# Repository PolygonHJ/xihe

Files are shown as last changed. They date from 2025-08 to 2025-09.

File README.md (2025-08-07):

# Xihe
**Xihe** is a self-sustaining, ultra-low-power sensing platform designed for long-lifetime deployments with zero maintenance. Powered by ambient energy sources such as solar or background RF, the system stores energy in supercapacitors until it reaches a threshold sufficient to activate, sense, and transmit data wirelessly. Once depleted, it enters a dormant state and repeats the cycle.

The system is designed to be as small and unobtrusive as possible, enabling it to be placed in an environment, monitor passively, and be forgotten—both visually and in terms of maintenance.

## System Overview
The platform consists of:

### 1. **Main Board — "Xihe-Core"**
- Hosts the energy harvesting and power management circuitry,
- Includes high-capacitance supercapacitor storage,
- Integrates a **Seeed XIAO nRF54L15** module for BLE/Zigbee communication,
- Provides a modular connector interface for sensor boards (I²C, SPI, UART, Analogue),
- Manages energy thresholds and system wakeup logic.

### 2. **Sensor Modules**
- Plug-in sensor boards for flexibility,
- Operate only during active energy windows to minimize load,
- Interchangeable to allow flexibility in deployment.

### 3. **Energy Storage Modules**
- Optional add-ons for extended runtime or energy reserve (Supercapacitors or Batteries),
- Connect to the side or bottom of the board for flexibility,
- Extend active life at the cost of increased physical size.

## Features
- ⚡ **Ambient Energy Harvesting**: Solar (single-cell) supported; RF harvesting planned,
- 🔋 **Supercapacitor-Based Power Storage**: Maintenance-free,
- 📡 **Low-Power Wireless Comms**: BLE/Zigbee-ready for periodic broadcast,
- 🧩 **Modular Sensing**: Swappable sensor boards and energy modules for application-specific deployments,
- 🔄 **Cyclic Operation**: Charge → Activate → Sense → Transmit → Sleep,
- ♻️ **Designed for Longevity**: No batteries, no wires, no maintenance

## Use Cases
The project is intended for low-effort, low-maintenance monitoring in home automation or other low-frequency sensing environments.

Example sensing applications:
- Light  
- Temperature  
- Humidity  
- Moisture  
- Open/Close (e.g. reed switch)  

## Status
The hardware is under active development. No hardware for software has been produced or tested yet.

# Future Ideas
- Energy storage modules,
- RF energy harvesting,
- Modularise harvesting and energy storage sections.

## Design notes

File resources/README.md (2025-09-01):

# Resources

- [Energy Harvester](./energy_harvester/): files related to the energy harvester chip (such as calculations).
- [PcbWay Manufacturing Files](./pcbway_manufacturing_rules/): reference rules file with PcbWays manufacturing capabilities.
- [Projects](./projects/): reference projects and exmaples;
  - [Proposal](./projects/Proposal/) is an initial concept design for a single sided board to test hardware with. This primarily was to test the USB-SWD circuit more easily, but the replacement on this sub-circuit with the Xiao nRF54L15 means the test design is less required.
  - [Xiao nRF54L15 Module](https://wiki.seeedstudio.com/xiao_nrf54l15_sense_getting_started/), an nRF54L15 module from seeed studio used for this project.
  - [BeeLight](https://github.com/Kampi/BeeLight), open source zigbee environment sensor.
  - [Pi Debug Probe](./projects/Pi%20Debugger), onboard USB-SWD schematics and firmware. 
  - [Solar nRF](https://github.com/PocketConcepts/Solar_nRF), low energy harvester example using the BQ25504.

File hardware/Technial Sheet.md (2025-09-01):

# Technical Sheet

> [!warning]
> External energy modules will need to have matching voltages with the on board super capacitor. The capacitor may be desoldered to improve available selection, but charging limits are still set by on-board resistors.

> [!warning]
> Sensor modules must work down to 2.5V to match the potential low threshold of operation as the super capacitor depletes.

## Power
Part selections detailed below. The following assumptions/decisions have been made:
- $50\mu A$ average power consumption (assumption),
- $1mW/cm^2$ power from ambient indoor lightning.

### Charging
Using the [KXOB25-03X4F-TR](https://waf-e.dubudisk.com/anysolar.dubuplus.com/techsupport@anysolar.biz/O18AzRx/DubuDisk/www/Gen3/KXOB25-03X4F%20DATA%20SHEET%2020210127.pdf) would generated approximately $0.25 \times 1m \times 1.39 = 347.5\mu W$.

The capacitor charge time can be calculated with:  
$Pt = \frac{1}{2}C(V_{final}-V_{initial})^2 \rightarrow t = \frac{CV^2}{2 \eta P}$

Where:
- $\eta$: Conversion efficiency; 80%,
- $V_{final}$: Final capacitor voltage; 5.3 based on set limits,
- $V_{initial}$: Initial capacitor voltage, 0V empty, or 2.5V for active system,
- $C$: Energy storage device capacitance; 470mF,
- $P$: Power from solar cell, $347.5\mu W$.

For an empty capacitor:  
$t = \frac{0.47 \times 5.3^2}{2 \times 0.8 \times 0.348m} = 6h36min$ to fully charge.

For the running systme ($V_{initial}=2.5$):  
$t = \frac{0.47 \times (5.3-2.5)^2}{2 \times 0.8 \times 0.348m} = 1h50min$ to fully charge.

> [!note] Note
> Ignores the energy being consumed by the system while charging.

### Discharging
For the system to fully use the available energy in the capacitor:  
$t = \frac{C \times (V_{initial}-V_{final})}{I_{avg}} = \frac{470m \times (5.3-2.5)}{50\mu} \approx 7h20min$

This assumes a $50\mu A$ average current draw based on a [forums post online](https://devzone.nordicsemi.com/f/nordic-q-a/122432/nrf54l15-zigbee---high-current-consumption) for a 1minute period zigbee transmittion achieving similar results.

Using the assumptions of:
- $40ms @ 10mA$ every 5minutes,
- $100ms @ 1mA$ every 5minutes,
- $10\mu A$ standby consumption.

$I_{avg} = \frac{40m \times 10m}{300} + \frac{100m \times 1m}{300} + 10\mu = 12\mu A$  

$t = \frac{470m \times (5.3-2.5)}{12\mu} \approx 30h28min$

## XIAO NRF54L15
The schematic for the [XIAO NRF54L15](https://files.seeedstudio.com/wiki/XIAO_nRF54L15/Getting_Start/nRF54L15_Schematic.pdf) is available online.

### Power
The MCU VDD pins are directly connected to the 3V3 pin on the SoM, therefore supply can be provided externally on this pin. There is some bulk capacitance ($10\mu F$ and $100nF$ here).

The potential leakage current that could feed from the energy storage element to the unrequired system (e.g. debugger) comes through the step down DC `VBUS` to `VSYS_3V3`. The circuit uses a [TPS62843](https://www.ti.com/lit/ds/symlink/tps62843.pdf) with an advertised leakage current of $0 \rarr 45nA$.

### User Button
The user button on the module will be used to put the device in pairing mode.

## Solar Cell
The [KXOB25-03X4F-TR](https://waf-e.dubudisk.com/anysolar.dubuplus.com/techsupport@anysolar.biz/O18AzRx/DubuDisk/www/Gen3/KXOB25-03X4F%20DATA%20SHEET%2020210127.pdf) was chosen for its dimensions and cost that would reasonably fit on the board. See the power section for information on generated power.

The device has:
-  a solar surface area of $0.528 \times 0.659 \times 4 = 1.39cm^2$,
-  25% efficiency.

## Harvester
The harvester is the [BQ25570](https://www.ti.com/lit/ds/symlink/bq25570.pdf). TI was chosen thanks to their good documentation. Of the TI range, the [BQ25570](https://www.ti.com/lit/ds/symlink/bq25570.pdf) offers a built in buck to reduce over-all circuit complexity. It also works with inputs from 100mV up to 5.5V.

The boost ([NRS4012T220MDGJ](https://mm.digikey.com/Volume0/opasdata/d220001/medias/docus/610/NRS4012T220MDGJ_SS.pdf)) and buck ([DFE252012F-100M=P2](https://www.murata.com/~/media/webrenewal/products/inductor/chip/tokoproducts/wirewoundmetalalloychiptype/m_dfe252012f.ashx)) inductors were chosen based on the recommended values in section 8.1.3 of the [BQ25570](https://www.ti.com/lit/ds/symlink/bq25570.pdf) datasheet.

The peripheral capacitors are chosen based on the recommended values in section 8.1.4 of the [BQ25570](https://www.ti.com/lit/ds/symlink/bq25570.pdf) datasheet.

TI provide a design help guide (SLUC484) on their [product page](https://www.ti.com/product/BQ25570#design-tools-simulation) (also found in the resources section of this repository) which is a calculator to help determine required resistor values.

> [!note]
> BoM consolidation on the resistor values can likely be done as a future cost saving exercise as the precision and requirements around these voltage settings is not absolutely strict. The initial values have been chosen to maximise the power saving benefit from the higher sum values.

### MPPT
The harvesting energy source is a solar cell ([KXOB25-03X4F-TR](https://waf-e.dubudisk.com/anysolar.dubuplus.com/techsupport@anysolar.biz/O18AzRx/DubuDisk/www/Gen3/KXOB25-03X4F%20DATA%20SHEET%2020210127.pdf)), therefore the MPPT can be set to 80% which can be achieved on the BQ25570 by tying the `VOC_SAMP` pin to `VSTOR`.

### VBAT_OV
The overvoltage is targeted at 5V5 to maximise the energy that can be stored in a 5V5 capacitor. 

To calculate the required resistor values: $\texttt{VBAT\_OV} = \frac{3}{2} \times 1.21 \left ( 1 + \frac{R_{OV2}}{R_{OV1}}\right )$ and $R_{OV1}+R_{OV2} < 13M\Omega$.

Allowing or a 1% tolerance on the resistors, this sets $R_{OV1}=4.22M\Omega$ and $R_{OV2}=8.2M\Omega$. This leads to a highest possible $\texttt{VBAT\_OV} = 5.4V$ and a nominal $\texttt{VBAT\_OV} = 5.3V$.

> [!warning] Warning
> If a battery module is to be connected, the value of these resistor will most likely need to be changed to support the supplied batteries safe limits.

### VBAT_OK_PROG & VBAT_OK_HYST
The `VBAT_OK_PROG` threshold sets the `VBAT_OK` signal low when the storage device is discharging and drops below the configured threshold.

The `VBAT_OK_HYST` threshold sets the `VBAT_OK` signal high when the storage device is charging and goes above the configured threshold.

The system shall be designed so that `VBAT_OK_PROG` = 3V3 and `VBAT_OK_HYST` = 2V5. Under the condition that the system is only able to charge up to 3V3, due to the available harvestable energy, this would give the system a 2hr dark time before hitting the 2V5 threshold where the MCU is alerted to no longer operate assuming it has an average current draw of $50\mu A$. It would then enter a powered sleep mode (estimed $I_{avg}=10\mu A$) where it could operate for 8hrs until it hits the `VBAT_UV` (1V9) threshold at which power is removed from the system.

The values can be calculated using the following equations (also in the design help guide):  
- $R_{OK1} + R_{OK2} + R_{OK3} < 13M\Omega$,
- $\texttt{VBAT\_OK\_PROG} = 1.31 \left ( 1 + \frac{R_{OK2}}{R_{OK1}} \right )$,
- $\texttt{VBAT\_OK\_HYST} = 1.31 \left ( 1 + \frac{R_{OK2} + R_{OK3}}{R_{OK1}} \right )$.

This leads to $R_{OK1}=4.7M\Omega$, $R_{OK2}=5.1M\Omega$, $R_{OK3}=3.0M\Omega$.

### VOUT
The system was chosen to operate at 2.5V to match the `VBAT_OK_PROG`, i.e. the system should always be operating at 2V5 unless it reaches a force sleep state.
The configuration resistor values can be calculated using:
- $R_{OUT1} + R_{OUT2} < 13M\Omega$
- $V_{OUT} = 1.21 \left ( \frac{R_{OUT1} + R_{OUT2}}{R_{OUT1}}\right )$

This leads to $R_{OUT1} = R_{OUT2} = 6.49M\Omega$. This sets the threshold to 2V4, but is close enough for the BoM consolidation benefit.

### VBAT_OK Signal
The `VBAT_OK` pin is controlled through a PFET to `VSTOR`. Therefore the output is held at `VSTOR` when the battery charge is above the configured threshold, and pulled to ground when the signal is below the configured threshold (i.e. an external pull resistor is not required).

The `VSTOR` voltage could range from $1.95V$ to $5.5V$ depending on the capacitor charge. Possible solutions are: NMOS/PMOS level shifter, zener diode, level shifter IC.

The possible options are reviewed below. Based on this, a level shifter will be used.

#### Zener
A 3V zener is the simplest solution, but means the input signal will not work when the `VSTOR` voltage drops below the MCU threshold for a high signal. Available diodes have a leakage current of $~800nA$.

#### Load switch
A high side PMOS load switch could be used. Even with a $1M\Omega$ resistor this will have a $1\mu A$ drain when `VBAT` is high.

An inverting NMOS switch will have the same $1\mu A$ drain. his could be done for ~£0.14.

#### Level Shifter
The [AXP1T34](https://www.digikey.co.uk/en/products/detail/nexperia-usa-inc/AXP1T34GMX/22216650) is a 100nA max leakage current load switch for £0.27 with an option for a package down to 1x1mm.

It is an active push-pull device so no pull resistors are required.

## USB Charger
The addition of the USB charger allows the device to be charged while being programmed or alternatively connected to an external wall charger.

The Xiao module have a built in USB charger that could be used, however, this is configured to only output up to 4V2. In order to maximise the potential energy that can be stored the [BQ25173](https://www.ti.com/lit/ds/slusdy6/slusdy6.pdf) has been added and configured to charge the capacitor up to 5V5.

### Current Limit
The current can be set through a configurable resistor.

$I_{CHG} = \frac{300}{R_{ISET}}$

Setting $R_{ISET}=3k\Omega$ puts the charge current at $100mA$.

This sets the charge time from empty to full to: $t = \frac{CV}{I_{CHG}} = \frac{0.47 \times 5}{100m} = 23.5seconds$.

### Voltage Limit
The charging voltage is set by: 
- $V_{REG} = 0.8 \times \frac{R_{FBT}+R_{FBB}}{R_{FBB}}$,
- $R_{FBT} + R_{FBB} < 1M\Omega$

Based on this, $R_{FBT} = 680k\Omega$ and $R_{FBB} = 120k\Omega$ for a voltage limit of 5V3.

> [!note]
> The output voltage cannot exceed the input voltage. It is assumed that the Xiao module only accepts 5V, therefore the super capacitor can be charged by the USB to more than 5V by the USB input. The potential divider chain is set 

> [!warning] 
> The `nPG` pin can be used as the bottom of the potential divider to prevent divider leakage from the supercapacitor when the charger is disabled. This pin has a maximum rating of 5V5, which means a higher voltage device cannot be connected as an energy module.

## Capacitor
The [EDC224Z5R5H](https://www.digikey.co.uk/en/products/detail/cornell-dubilier-knowles/EDC224Z5R5H/10412911) is a 470mF 5.5V capacitor which sits at approximately the same off board height as the USB connector. Therefore it should have minimal impact on overall board size. 

### Possible Substitutes
- [KR-5R5H474-R](https://www.digikey.co.uk/en/products/detail/eaton-electronics-division/KR-5R5H474-R/1556249),
- [SCE5R5H474](https://www.digikey.co.uk/en/products/detail/sruite-electronic-technology-us/SCE5R5H474/13901746)/[AliExpress](https://www.aliexpress.com/item/1005007532080868.html) (**UNCLEAR** if dimensionally compatible),
- [PSB401010H](https://www.maxell.eu/news/maxell-developed-long-life-all-solid-state-battery-based-module-for-industrial-equipment-power-backup/) is a solid state battery which looks like a very interesting and form suitable alternative but does not appear to be available for purchase yet.

## Energy Module Connector
A few options are valid for the energy module connector.

A right angle 0.1" header is a simple, cheap option which should have low risk of short. The [801-83-002-20-001101](https://www.mouser.co.uk/ProductDetail/Preci-dip/801-83-002-20-001101) is an option which fits in the available space on the board.

### Other options
- [Pogo Mates](https://www.aliexpress.com/item/1005003656767263.html) seem good, but this part has poor documented dimensions and high risk of shorting.
- [Pogo Pin](https://precidip.com/product/811-ss-002-20-679101/) something like this could be used on the module side.

# Ambient Sense Module  
The ambient sense module is an initial design with a few different sensors to help with development.

The board has a reed switch (for open/close detection), a humidity/temperature sensor and a light sensor. The sensors will use I2C for simplicity with a $10k \Omega$ pull-up.

## Reed
[RI80SMDM-0510-J1](https://comus-intl.com/wp-content/uploads/2017/04/RI-80SMDM.pdf) is a normally open small formfactor reed switch. Ideally a lower profile switch can be found but this is suitable for now. It is connected to a GPIO pin which is to be configured an an input. It is default pulled down, and pulls high on switch closure.

## Light  
[OPT3002](https://www.ti.com/lit/ds/symlink/opt3002.pdf) is a light to digital sensor that can measure light in the range 300nm to 1000nm at power levels from $1.2nW/cm^2$ to $10mW/cm^2$.

The sensor was chosen for it's I2C, low voltage and low power operation:
- $V_{supply}$ down to 1.6V,
- Quiescent current in shutdown <500nA.

It can be run in continuous or single shot mode. Single shot mode will be used to reduce overall power consumption.

## Temperature / Humidity
[HDC2010](https://www.ti.com/lit/ds/symlink/hdc2010.pdf) is a humidity and temperature digital sensor. It can measure for $-40\degree C$ to $125\degree C$ and $0-100\%$. 

The sensor was chosen for it's I2C, low voltage and low power operation:
- $V_{supply}$ down to 1.6V,
- Quiescent current in shutdown <100nA.

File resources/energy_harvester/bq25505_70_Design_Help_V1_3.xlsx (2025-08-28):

User Input | VBIAS | 1.21 | V
Fixed
 | Comparator threshold for VSTOR of charger. |  |  |  |  | Comparator threshold voltages indicating when |  |  |  |  | For the bq25570 only, comparator threshold |  |  |  |  | Maximum power point threshold, e.g. ~0.7-0.8 of
 | Typically the max storage element voltage, |  |  |  |  | VSTOR has risen above VBAT_OK_HYST or fallen |  |  |  |  | for VOUT of buck converter. |  |  |  |  | solar panel's open circuit voltage.
 | e.g. 4.2V for LiIon battery. |  |  |  |  | below VBAT_OK.
 | VBAT_UV < VBAT_OV < 5.5V |  |  |  |  | VBAT_OV > VBAT_OK_HYST > VBAT_UV |  |  |  |  | 1.3V < VOUT < VBAT_OV |  |  |  |  | MPPT
Desired |  |  |  |  |  | RSUM1 | 13 | MW |  |  |  |  |  |  |  | RSUM1 | 20 | MW
Desired | RSUM1 | 13 | MW |  |  | VBAT_OK | 2.5 | V | > VBAT_UV |  | RSUM1 | 13 | MW |  |  | VIN_DC(OC) | 1 | V | Open Circuit Volts
Desired | VBAT_OV | 5.5 | V |  |  | VBAT_OK_HYST | 3.3 | V | > VBAT_OK |  | VOUT | 2.5 | V |  |  | VREF_SAMP | 0.8 | V | MPP voltage
 |  |  |  |  |  |  |  | closest 1% resistor1 |  |  |  |  |  |  |  |  |  | closest 1% resistor1
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

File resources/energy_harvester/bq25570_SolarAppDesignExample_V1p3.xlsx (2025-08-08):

User Input
Computed/Fixed
 |  |  | VSTOR nominal | 3.00 | V |  |  |  |  | VBAT_UV < VSTOR nominal <= VBAT_OV
System Loads | VOUT (V) | IOUT (mA) | Est Buck Effcy per datasheet | ISTOR = (VOUTxIOUT) / (VSTORnom x Effcy) (mA) | Mode Duration (how long?) (s) | Mode Period (how often?) (s) | Mode Hours / Day = 24 hours x duration/ period | mAHr / Day = ISTOR X Mode Hrs / Day | mWHr / Day = VSTOR x mAHr / Day
Active Mode 1 - bq25570 VOUT | 3.300 | 10.000 | 0.930 | 11.828
Active Mode 1 - bq25570 VSTOR |  |  |  | 0.000 |  |  |  |  |  | Direct loading on VSTOR
Totals for Active Mode 1 |  |  |  | 11.828 | 0.040 | 300.000 | 0.003 | 0.038 | 0.114
Active Mode 2 - bq25570 VOUT | 3.300 | 1.000 | 0.850 | 1.294 |  |  |  |  |  | If only one active mode, enter 0 for IOUT.
Active Mode 2 - bq25570 VSTOR |  |  |  | 0.000 |  |  |  |  |  | If only one active mode, enter 0 for ISTOR.
Totals for Active Mode 2 |  |  |  | 1.294 | 0.100 | 300.000 | 0.008 | 0.010 | 0.031
Sleep Mode - bq25570 VSTOR (1.8V rail off) |  |  |  | 0.010 |  |  | 23.989 | 0.240 | 0.720 | Idle mode hours / day = 24 minus active mode hours / day
bq25570 quiescent current + storage element leakage current |  |  |  | 0.001 |  |  | 24.000 | 0.024 | 0.072 | Storage element leaks all the time.
 | Total mAHr / day consumed |  |  |  |  |  |  | 0.312 | mAHr / day
 | Multiply by max consec dark days (e.g. not charging when overcast or raining) |  |  |  |  |  |  | 2.000 | days / week
 | Recommended minimum battery capacity |  |  |  |  |  |  | 0.624 | mAHr
 | -OR-
 | Mininum super capacitor voltage |  |  |  |  |  |  | 2.500 | V | VBAT_UV = 2.0V > Min super capacitor > VSTOR nominal
 | Maximum super capacitor voltage |  |  |  |  |  |  | 5.500 | V | VSTOR nominal < Max super capacitor voltage <= VBAT_OV
 | Recommended minimum super capacitance |  |  |  |  |  |  | 0.562 | F | Min Bat Capacity / 1000 x 3600s/hr x VSTORNOM = 1/2 x CSUPER x (Vmax2 - Vmin2)
 |  | Total mWHr / day consumed |  |  |  |  |  |  | 0.936 | mWHr / day
 |  | Multiply by operating days per week |  |  |  |  |  |  | 7.000 | days / week
 |  | Total mWHr /week required for system operation for the week |  |  |  |  |  |  | 6.554 | mWHr / week
 |  | Divide by charging days per week |  |  |  |  |  |  | 5.000 | days / week | Operating days minus max consecutive dark days
 |  | Total mWHr / day required to be collected by solar panel during charging days |  |  |  |  |  |  | 1.311 | mWHr / day | Total 7-day power must be collected during 5 charging days
 |  | Divide by charging hours / day |  |  |  |  |  |  | 8.000 | hours / day | i.e., includes excess energy for charging the battery
 |  | Instantaneous power required from the solar panel |  |  |  |  |  |  | 0.164 | mW
 |  |  | Divide by low estimate of bq25570 efficiency per datasheet |  |  |  |  |  | 0.800
 |  |  | Minimum input power required for system operation |  |  |  |  |  | 0.205 | mW
 |  |  |  | Divide by panel power per panel datasheet |  |  |  |  | 1.000 | mW/cm2 | Use power from lowest expected light level
 |  |  |  | Minimum solar panel area required |  |  |  |  | 0.205 | cm2

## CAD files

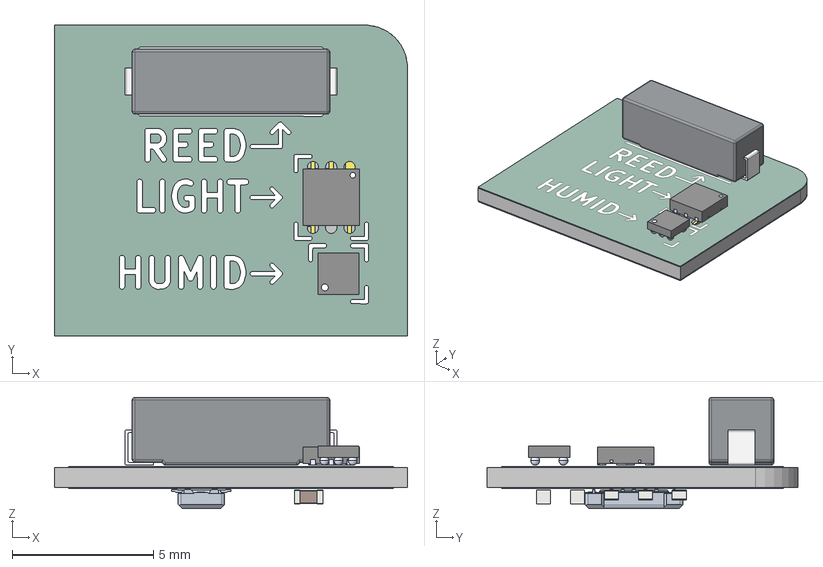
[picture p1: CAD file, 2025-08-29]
hardware/mechanical/ambient.step
12.5 x 11.0 x 3.94 mm
TI_6DSBGA_YPA
TI_6USON_DNP
Leg
R_0402_1005Metric x 3
C_0402_1005Metric x 2
ambient_copper
ambient_via
ambient_silkscreen
ambient_soldermask
ambient_PCB

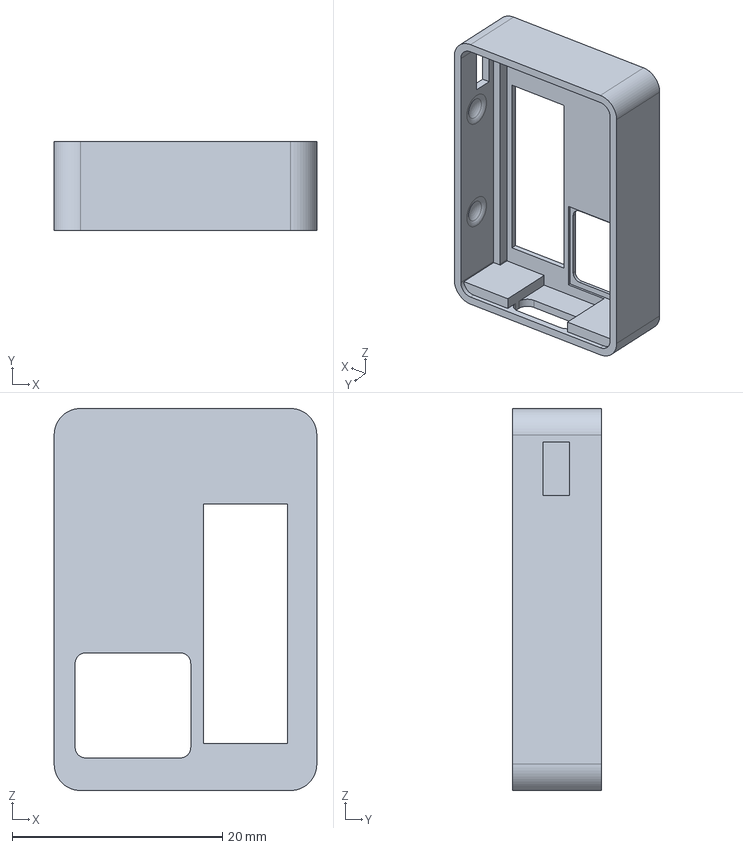
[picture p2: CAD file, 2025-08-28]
hardware/mechanical/case_body.step
25.0 x 8.49 x 36.4 mm

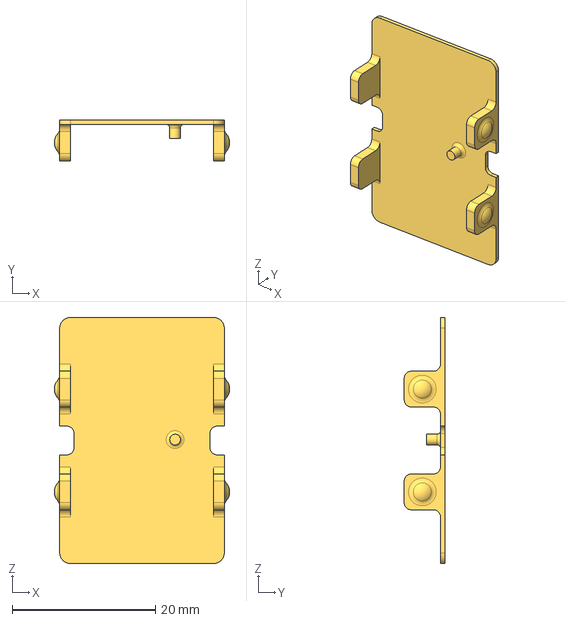
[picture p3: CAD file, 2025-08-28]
hardware/mechanical/case_lid.step
24.5 x 5.67 x 34.4 mm

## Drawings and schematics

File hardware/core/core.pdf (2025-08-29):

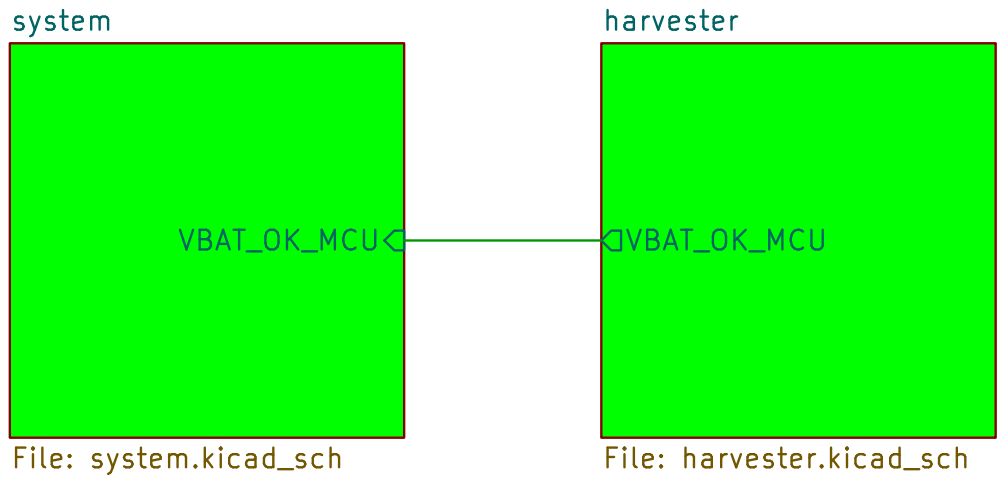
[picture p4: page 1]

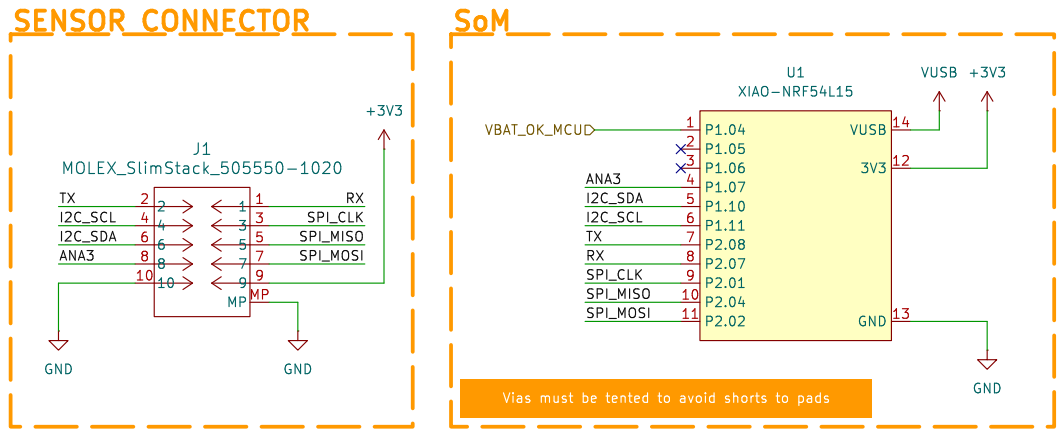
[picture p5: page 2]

I2C_SCL Vias must be tented to avoid shorts to pads

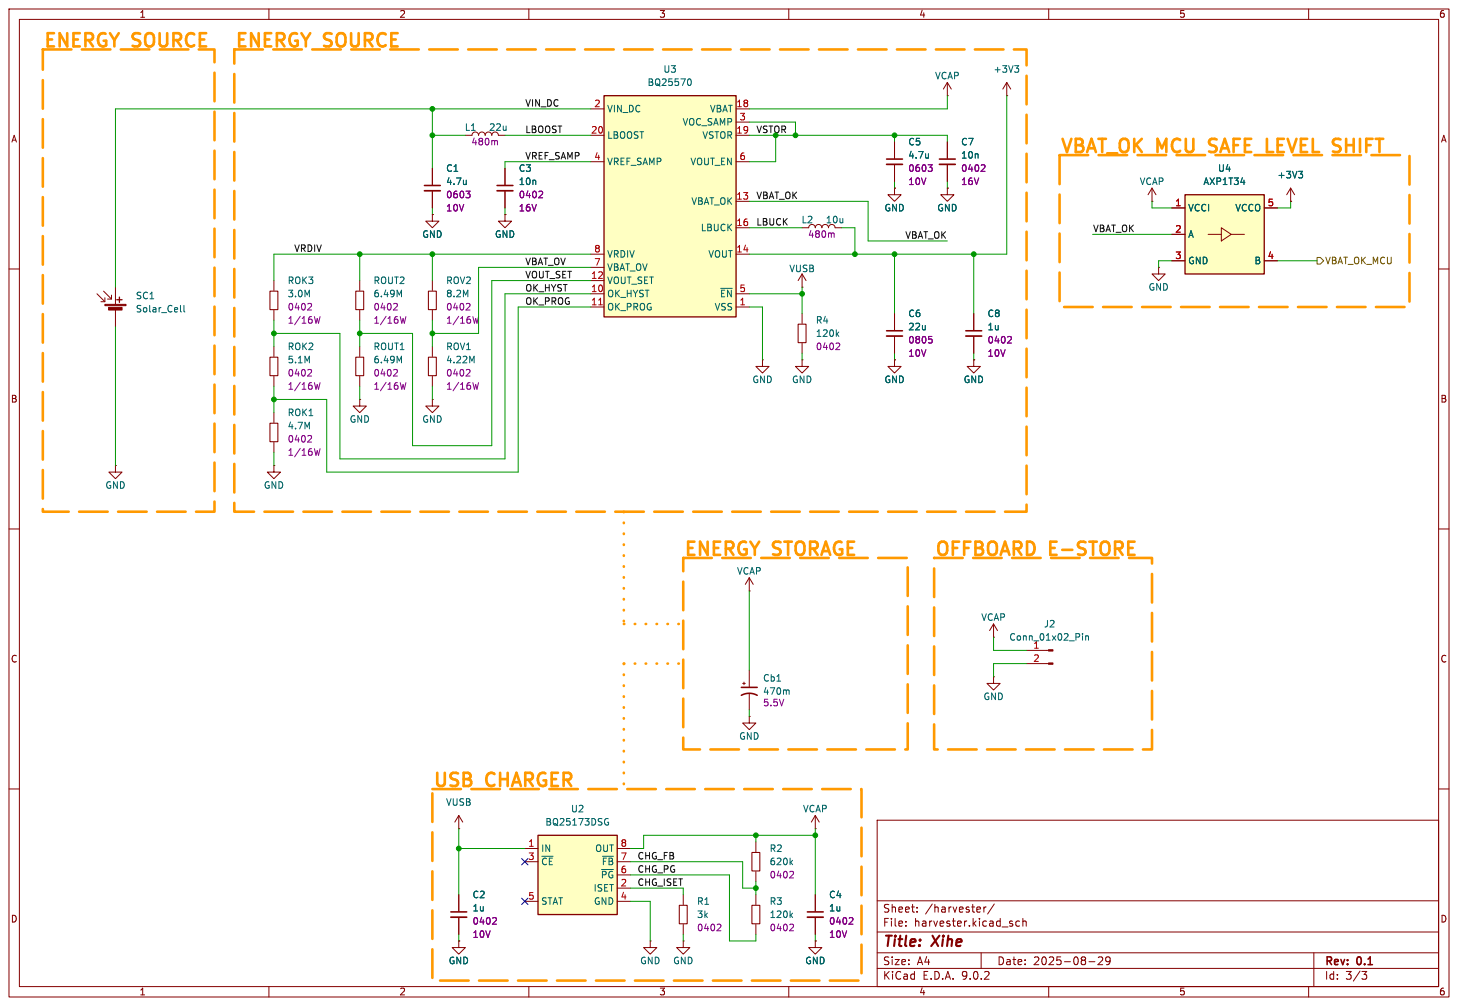
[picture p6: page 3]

ENERGY SOURCE

File: harvester.kicad_sch Sheet: /harvester/ GND

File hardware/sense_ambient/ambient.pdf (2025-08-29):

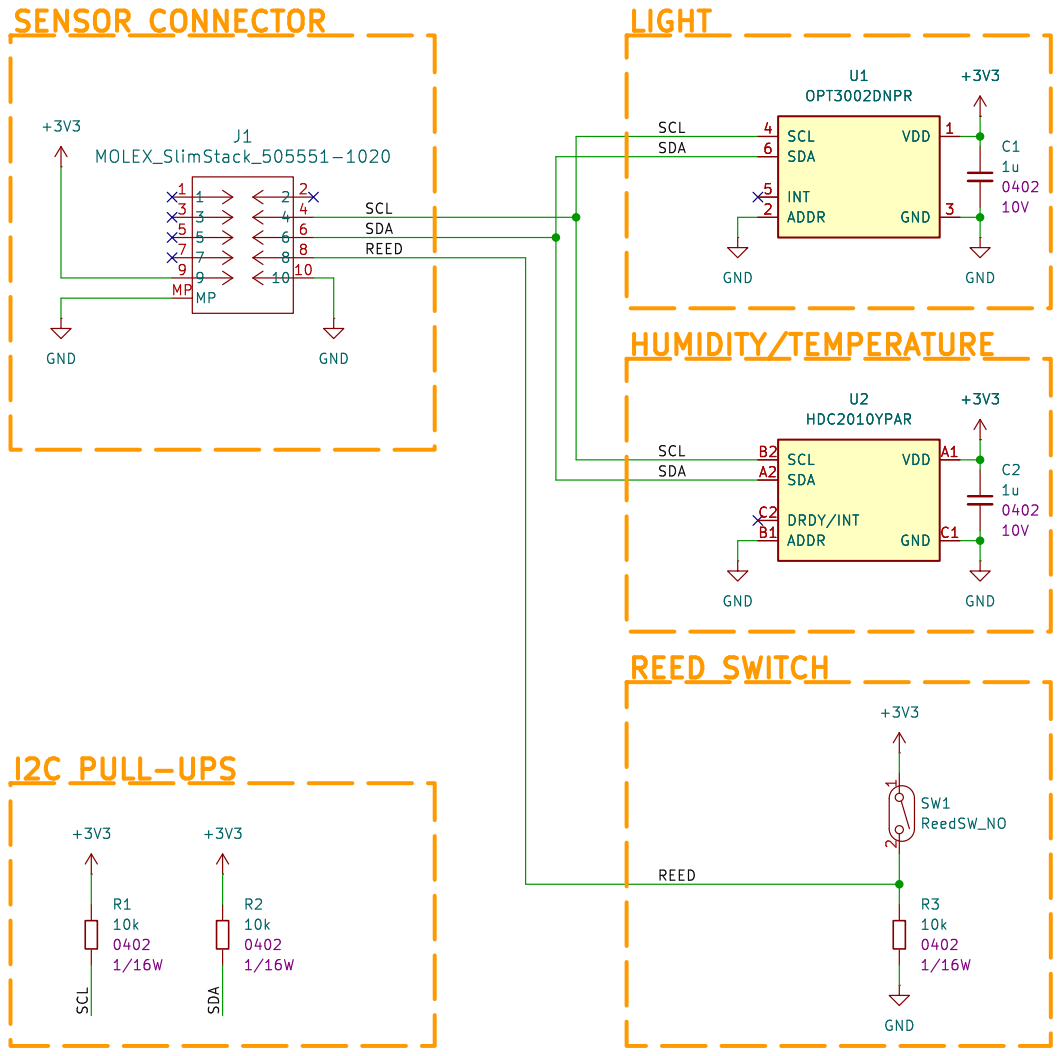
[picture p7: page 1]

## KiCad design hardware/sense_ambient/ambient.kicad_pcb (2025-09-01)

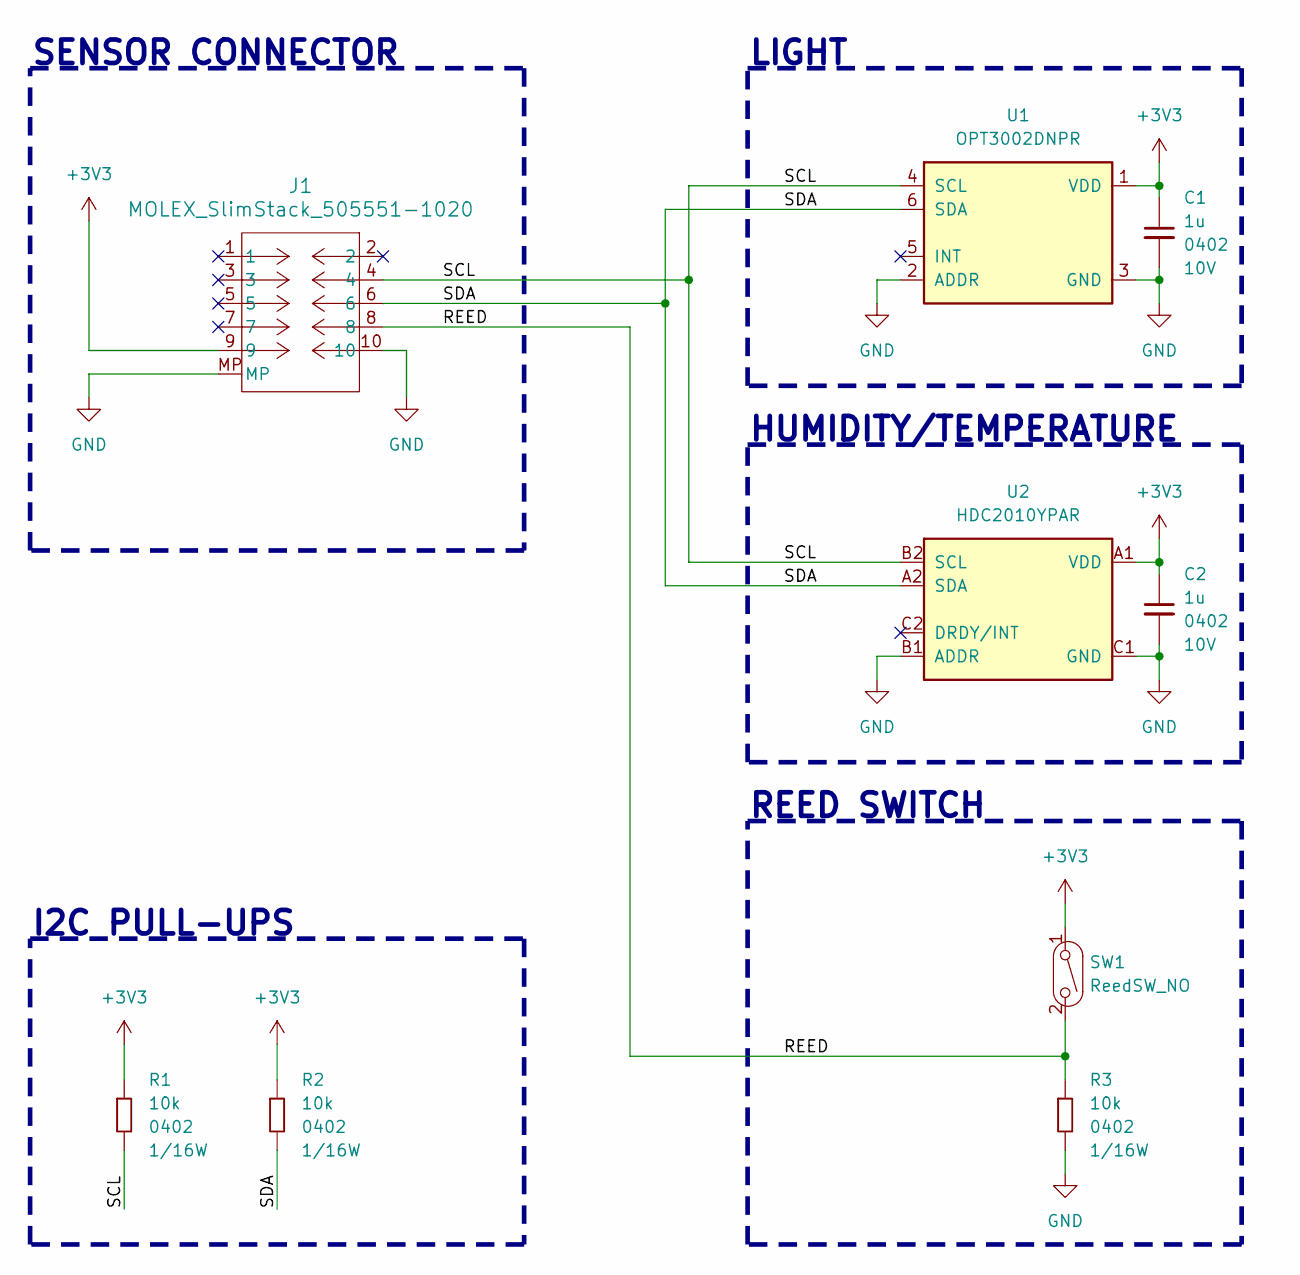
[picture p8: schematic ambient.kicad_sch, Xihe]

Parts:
C1, C2: 1u; C_0402_1005Metric; Voltage Rating 10V; Part Number GRM155Z71A105KE01J
J1: MOLEX_SlimStack_505551-1020; Part Number 5055511020
R1, R2, R3: 10k; R_0402_1005Metric; Part Number RC0402FR-0710KP
SW1: ReedSW_NO; COMUS_RI80SMDM0510J1; Part Number RI80SMDM-0510-J1
U1: OPT3002DNPR; TI_6USON_DNP; Part Number OPT3002DNPR
U2: HDC2010YPAR; TI_6DSBGA_YPA; Part Number HDC2010YPAR

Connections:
+3V3: C1.1, C2.1, J1.9, R1.1, R2.1, SW1.1 (A), U1.1 (VDD), U2.A1 (VDD)
/REED: J1.8, R3.1, SW1.2 (B)
/SCL: J1.4, R1.2, U1.4 (SCL), U2.B2 (SCL)
/SDA: J1.6, R2.2, U1.6 (SDA), U2.A2 (SDA)
GND: C1.2, C2.2, J1.10, J1.MP, R3.2, U1.2 (ADDR), U1.3 (GND), U1.7 (GND), U2.B1 (ADDR), U2.C1 (GND)

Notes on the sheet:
REED SWITCH
SENSOR CONNECTOR
I2C PULL-UPS
HUMIDITY/TEMPERATURE
LIGHT

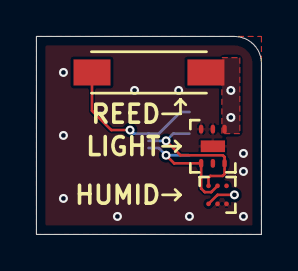
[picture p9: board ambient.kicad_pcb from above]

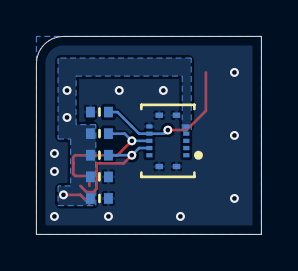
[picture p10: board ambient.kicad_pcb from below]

Board: 2 copper layers, 12.5 x 11.0 mm, 9 parts (6 on the bottom side), 5 nets.

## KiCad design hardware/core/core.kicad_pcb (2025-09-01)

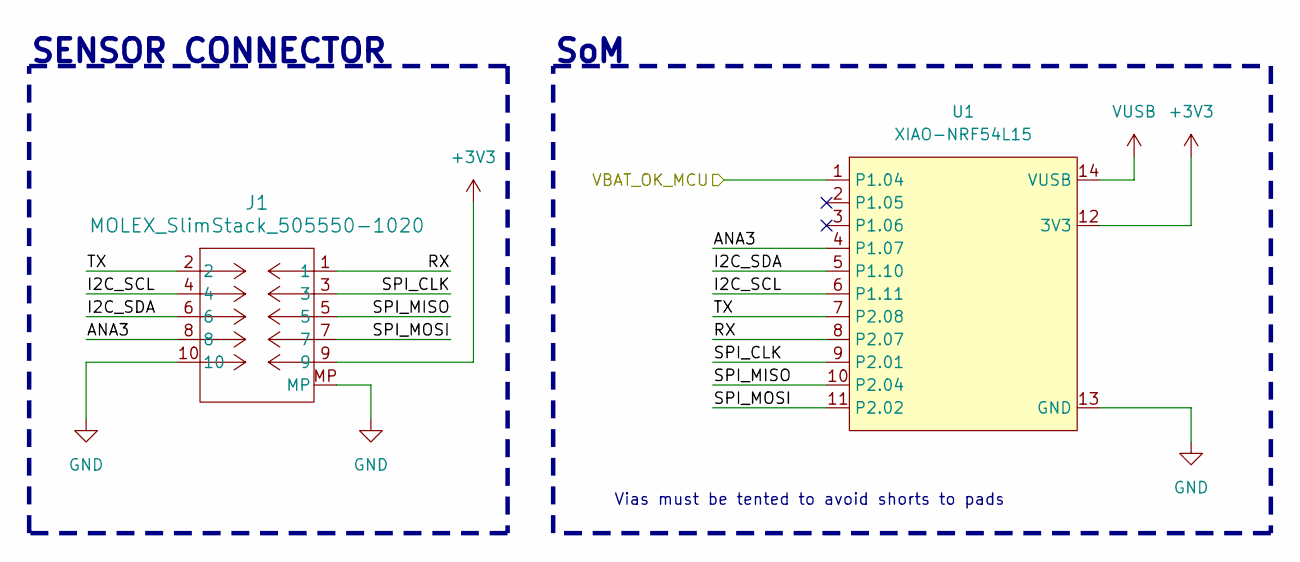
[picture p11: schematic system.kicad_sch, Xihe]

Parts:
J1: MOLEX_SlimStack_505550-1020; Part Number 5055501020
U1: XIAO-NRF54L15; XIAO-NRF54L15-DIP; Part Number XIAO-NRF54L15

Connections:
+3V3: J1.9, U1.12 (3V3); also elsewhere on the board
/harvester/VBAT_OK_MCU: U1.1 (P1.04); also elsewhere on the board
/system/ANA3: J1.8, U1.4 (P1.07)
/system/I2C_SCL: J1.4, U1.6 (P1.11)
/system/I2C_SDA: J1.6, U1.5 (P1.10)
/system/RX: J1.1, U1.8 (P2.07)
/system/SPI_CLK: J1.3, U1.9 (P2.01)
/system/SPI_MISO: J1.5, U1.10 (P2.04)
/system/SPI_MOSI: J1.7, U1.11 (P2.02)
/system/TX: J1.2, U1.7 (P2.08)
GND: J1.10, J1.MP, U1.13 (GND); also elsewhere on the board
VUSB: U1.14 (VUSB); also elsewhere on the board

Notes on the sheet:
SoM
SENSOR CONNECTOR
Vias must be tented to avoid shorts to pads

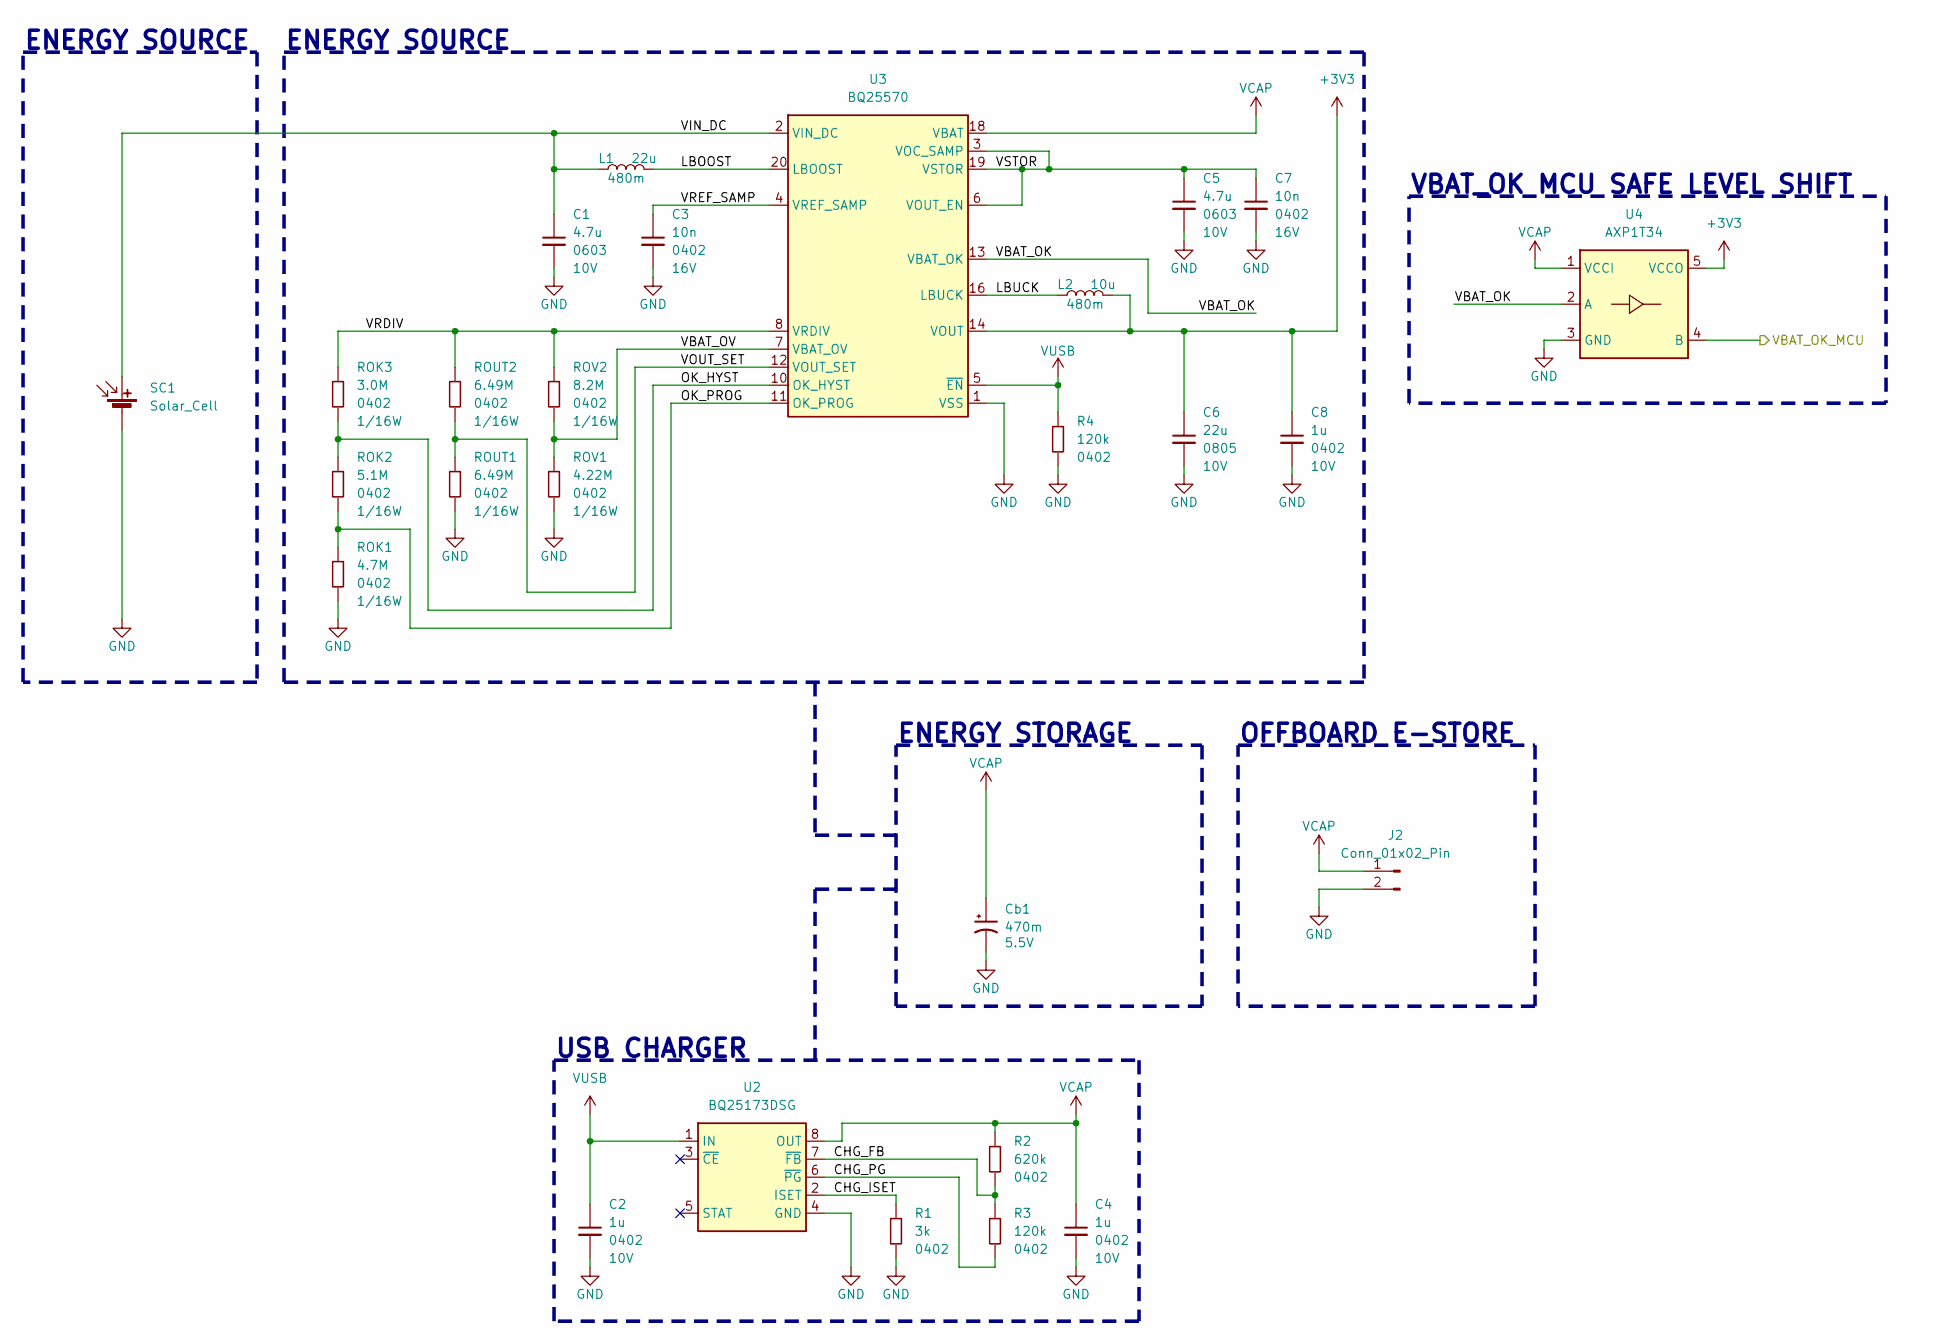
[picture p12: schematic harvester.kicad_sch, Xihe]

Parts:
C1, C5: 4.7u; C_0603_1608Metric; Voltage Rating 10V; Part Number GRM188Z71A475ME15D
C2, C4, C8: 1u; C_0402_1005Metric; Voltage Rating 10V; Part Number GRM155Z71A105KE01J
C3, C7: 10n; C_0402_1005Metric; Voltage Rating 16V; Part Number GRM155R71C103KA01D
C6: 22u; C_0805_2012Metric; Voltage Rating 10V; Part Number GRM21BZ71A226ME15L
Cb1: 470m; EATON_KR5R5H474R; Voltage Rating 5.5V; Part Number EDC474Z5R5H
J2: Conn_01x02_Pin; PD_801-83-002-20-001101; Part Number 801-83-002-20-001101
L1: 22u; TY_Inductor_NRS4012; Part Number NRS4012T220MDGJ
L2: 10u; L_1008_2520Metric; Part Number DFE252012F-100M=P2
R1: 3k; R_0402_1005Metric; Part Number RC0402FR-133KL
R2: 620k; R_0402_1005Metric; Part Number RC0402FR-07620KL
R3, R4: 120k; R_0402_1005Metric; Part Number RC0402FR-07120KL
ROK1: 4.7M; R_0402_1005Metric; Part Number RC0402FR-074M7L
ROK2: 5.1M; R_0402_1005Metric; Part Number RC0402FR-075M1L
ROK3: 3.0M; R_0402_1005Metric; Part Number RC0402FR-073ML
ROUT1, ROUT2: 6.49M; R_0402_1005Metric; Part Number RC0402FR-076M49L
ROV1: 4.22M; R_0402_1005Metric; Part Number RC0402FR-074M22L
ROV2: 8.2M; R_0402_1005Metric; Part Number RC0402FR-078M2L
SC1: Solar_Cell; ANYSOLAR_KXOB25; Part Number KXOB25-03X4F-TR
U2: BQ25173DSG; TI_8WSON_DSG; Part Number BQ25173DSGR
U3: BQ25570; TI_20VQFN_RGR; Part Number BQ25570RGRR
U4: AXP1T34; NX_5SOT353; Part Number 74AXP1T34GWH

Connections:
+3V3: C6.1, C8.1, L2.2, U3.14 (VOUT), U4.5 (VCCO); also elsewhere on the board
/harvester/CHG_FB: R2.2, R3.1, U2.7 (~FB)
/harvester/CHG_ISET: R1.1, U2.2 (ISET)
/harvester/CHG_PG: R3.2, U2.6 (~PG)
/harvester/LBOOST: L1.2, U3.20 (LBOOST)
/harvester/LBUCK: L2.1, U3.16 (LBUCK)
/harvester/OK_HYST: ROK2.1, ROK3.2, U3.10 (OK_HYST)
/harvester/OK_PROG: ROK1.1, ROK2.2, U3.11 (OK_PROG)
/harvester/VBAT_OK: U3.13 (VBAT_OK), U4.2 (A)
/harvester/VBAT_OK_MCU: U4.4 (B); also elsewhere on the board
/harvester/VBAT_OV: ROV1.1, ROV2.2, U3.7 (VBAT_OV)
/harvester/VIN_DC: C1.1, L1.1, SC1.1 (+), U3.2 (VIN_DC)
/harvester/VOUT_SET: ROUT1.1, ROUT2.2, U3.12 (VOUT_SET)
/harvester/VRDIV: ROK3.1, ROUT2.1, ROV2.1, U3.8 (VRDIV)
/harvester/VREF_SAMP: C3.1, U3.4 (VREF_SAMP)
/harvester/VSTOR: C5.1, C7.1, U3.3 (VOC_SAMP), U3.6 (VOUT_EN), U3.19 (VSTOR)
GND: C1.2, C2.2, C3.2, C4.2, C5.2, C6.2, C7.2, C8.2, Cb1.2, J2.2, R1.2, R4.2, ROK1.2, ROUT1.2, ROV1.2, SC1.2 (-), U2.4 (GND), U2.9 (GND), U3.1 (VSS), U3.9 (VSS), U3.15 (VSS), U3.17 (VSS), U3.21 (VSS), U4.3 (GND); also elsewhere on the board
VCAP: C4.1, Cb1.1, J2.1, R2.1, U2.8 (OUT), U3.18 (VBAT), U4.1 (VCCI)
VUSB: C2.1, R4.1, U2.1 (IN), U3.5 (~EN); also elsewhere on the board

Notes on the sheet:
VBAT_OK MCU SAFE LEVEL SHIFT
ENERGY STORAGE
OFFBOARD E-STORE
ENERGY SOURCE
USB CHARGER

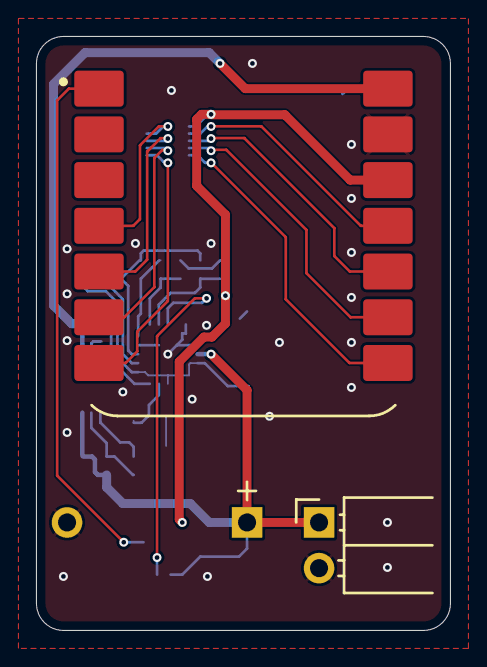
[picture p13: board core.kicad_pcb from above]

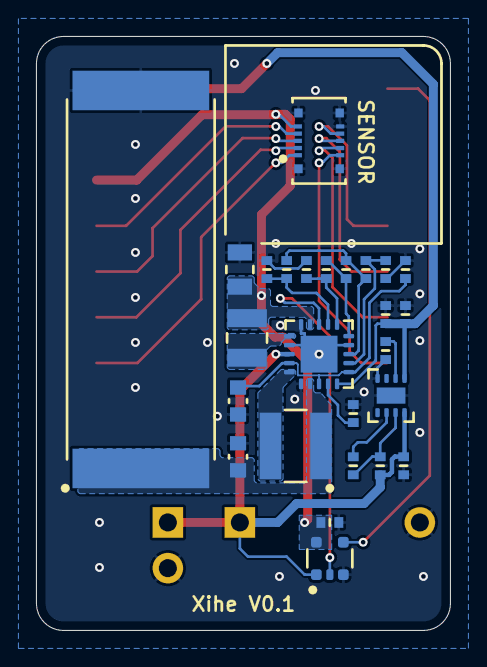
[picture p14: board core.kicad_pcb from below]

Board: 2 copper layers, 23.0 x 33.0 mm, 29 parts (26 on the bottom side), 27 nets.

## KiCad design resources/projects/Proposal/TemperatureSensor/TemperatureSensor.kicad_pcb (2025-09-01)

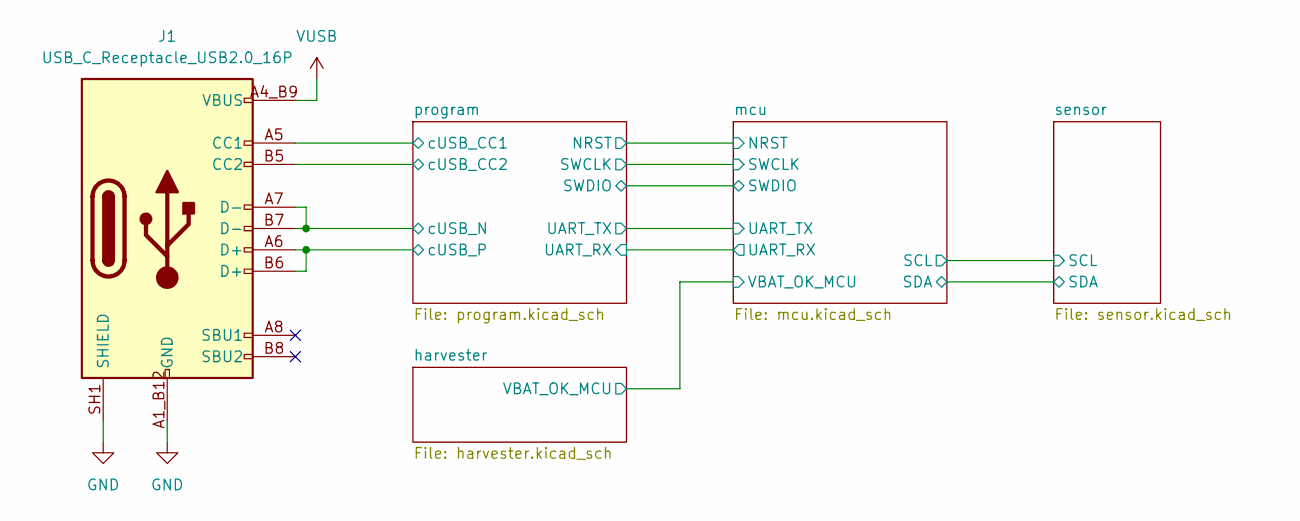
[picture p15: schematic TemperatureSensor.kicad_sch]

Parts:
J1: USB_C_Receptacle_USB2.0_16P; GCT_USB4105-GF-A; Part Number USB4105-GF-A

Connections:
/program/cUSB_CC1: J1.A5 (CC1); also elsewhere on the board
/program/cUSB_CC2: J1.B5 (CC2); also elsewhere on the board
/program/cUSB_N: J1.A7 (D-), J1.B7 (D-); also elsewhere on the board
/program/cUSB_P: J1.A6 (D+), J1.B6 (D+); also elsewhere on the board
GND: J1.A1_B12 (GND), J1.B1_A12 (GND), J1.SH1 (SHIELD), J1.SH2 (SHIELD), J1.SH3 (SHIELD), J1.SH4 (SHIELD); also elsewhere on the board
VUSB: J1.A4_B9 (VBUS), J1.B4_A9 (VBUS); also elsewhere on the board

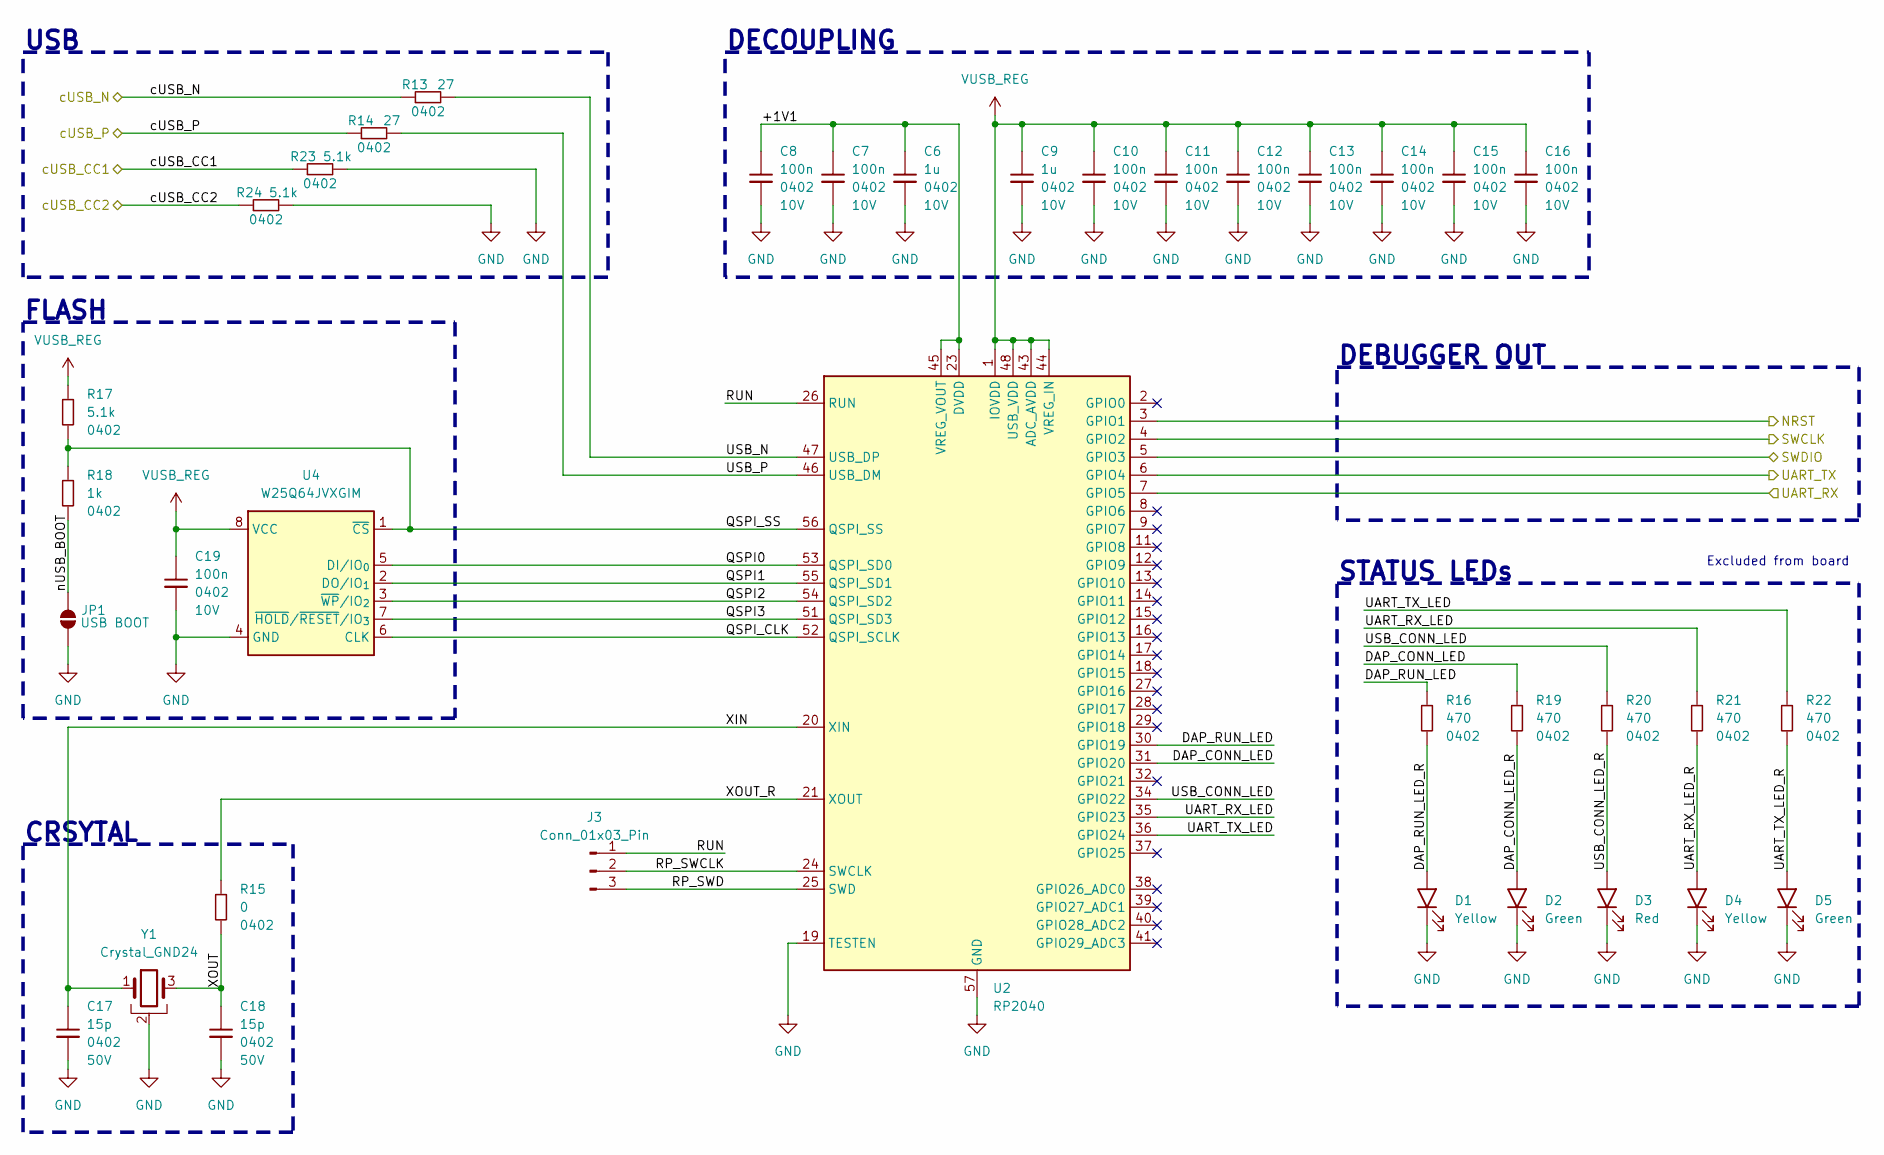
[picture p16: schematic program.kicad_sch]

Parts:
C6, C9: 1u; C_0402_1005Metric; Voltage Rating 10V; Part Number GRM155Z71A105KE01J
C7, C8, C10, C11, C12, C13, C14, C15, C16, C19: 100n; C_0402_1005Metric; Voltage Rating 10V; Part Number GRM155R71A104KA01J
C17, C18: 15p; C_0402_1005Metric; Voltage Rating 50V; Part Number GJM1555C1H150GB01D
D1, D4: Yellow; LED_0402_1005Metric
D2, D5: Green; LED_0402_1005Metric
D3: Red; LED_0402_1005Metric
J3: Conn_01x03_Pin; PinHeader_1x03_P2.54mm_Vertical
JP1: SolderJumper_2_Open; SolderJumper2_Open_0402
R13, R14: 27; R_0402_1005Metric; Part Number RC0402FR-0727RL
R15: 0; R_0402_1005Metric; Part Number RC0402FR-070RL
R16, R19, R20, R21, R22: 470; R_0402_1005Metric; Part Number RC0402FR-07470RL
R17, R23, R24: 5.1k; R_0402_1005Metric; Part Number RC0402FR-135K1L
R18: 1k; R_0402_1005Metric; Part Number RC0402FR-131KL
U2: RP2040; QFN-56-1EP_7x7mm_P0.4mm_EP3.2x3.2mm; Part Number SC0914(13)
U4: W25Q64JVXGIM; XSON-8-1EP_4x4mm_P0.8; Part Number W25Q64JVXGIM
Y1: Crystal_GND24; Crystal_SMD_Abracon_ABM8; Part Number ABM8-272-T3

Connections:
/mcu/NRST: U2.3 (GPIO1); also elsewhere on the board
/mcu/SWCLK: U2.4 (GPIO2); also elsewhere on the board
/mcu/SWDIO: U2.5 (GPIO3); also elsewhere on the board
/mcu/UART_RX: U2.7 (GPIO5); also elsewhere on the board
/mcu/UART_TX: U2.6 (GPIO4); also elsewhere on the board
/program/+1V1: C6.1, C7.1, C8.1, U2.23 (DVDD), U2.45 (VREG_VOUT), U2.50 (DVDD)
/program/DAP_CONN_LED: R19.1, U2.31 (GPIO20)
/program/DAP_CONN_LED_R: D2.2 (A), R19.2
/program/DAP_RUN_LED: R16.1, U2.30 (GPIO19)
/program/DAP_RUN_LED_R: D1.2 (A), R16.2
/program/QSPI0: U2.53 (QSPI_SD0), U4.5 (DI/IO_{0})
/program/QSPI1: U2.55 (QSPI_SD1), U4.2 (DO/IO_{1})
/program/QSPI2: U2.54 (QSPI_SD2), U4.3 (~WP/IO_{2})
/program/QSPI3: U2.51 (QSPI_SD3), U4.7 (~HOLD/~RESET/IO_{3})
/program/QSPI_CLK: U2.52 (QSPI_SCLK), U4.6 (CLK)
/program/QSPI_SS: R17.2, R18.1, U2.56 (QSPI_SS), U4.1 (~CS)
/program/RP_SWCLK: J3.2, U2.24 (SWCLK)
/program/RP_SWD: J3.3, U2.25 (SWD)
/program/RUN: J3.1, U2.26 (RUN)
/program/UART_RX_LED: R21.1, U2.35 (GPIO23)
/program/UART_RX_LED_R: D4.2 (A), R21.2
/program/UART_TX_LED: R22.1, U2.36 (GPIO24)
/program/UART_TX_LED_R: D5.2 (A), R22.2
/program/USB_CONN_LED: R20.1, U2.34 (GPIO22)
/program/USB_CONN_LED_R: D3.2 (A), R20.2
/program/USB_N: R13.2, U2.47 (USB_DP)
/program/USB_P: R14.2, U2.46 (USB_DM)
/program/XIN: C17.1, U2.20 (XIN), Y1.1
/program/XOUT: C18.1, R15.2, Y1.3
/program/XOUT_R: R15.1, U2.21 (XOUT)
/program/cUSB_CC1: R23.1; also elsewhere on the board
/program/cUSB_CC2: R24.1; also elsewhere on the board
/program/cUSB_N: R13.1; also elsewhere on the board
/program/cUSB_P: R14.1; also elsewhere on the board
/program/nUSB_BOOT: JP1.2 (B), R18.2
GND: C6.2, C7.2, C8.2, C9.2, C10.2, C11.2, C12.2, C13.2, C14.2, C15.2, C16.2, C17.2, C18.2, C19.2, D1.1 (K), D2.1 (K), D3.1 (K), D4.1 (K), D5.1 (K), JP1.1 (A), R23.2, R24.2, U2.19 (TESTEN), U2.57 (GND), U4.4 (GND), U4.9 (GND), Y1.2, Y1.4; also elsewhere on the board
VUSB_REG: C9.1, C10.1, C11.1, C12.1, C13.1, C14.1, C15.1, C16.1, C19.1, R17.1, U2.1 (IOVDD), U2.10 (IOVDD), U2.22 (IOVDD), U2.33 (IOVDD), U2.42 (IOVDD), U2.43 (ADC_AVDD), U2.44 (VREG_IN), U2.48 (USB_VDD), U2.49 (IOVDD), U4.8 (VCC); also elsewhere on the board

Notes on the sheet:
CRSYTAL
STATUS LEDs
DECOUPLING
FLASH
USB
DEBUGGER OUT
Excluded from board

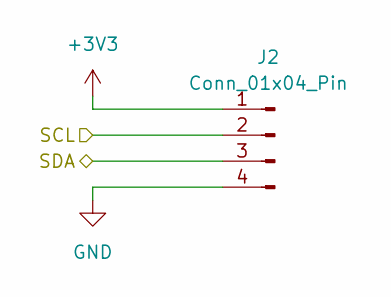
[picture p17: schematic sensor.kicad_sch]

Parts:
J2: Conn_01x04_Pin; PinHeader_1x04_P2.54mm_Vertical

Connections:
+3V3: J2.1; also elsewhere on the board
/mcu/SCL: J2.2; also elsewhere on the board
/mcu/SDA: J2.3; also elsewhere on the board
GND: J2.4; also elsewhere on the board

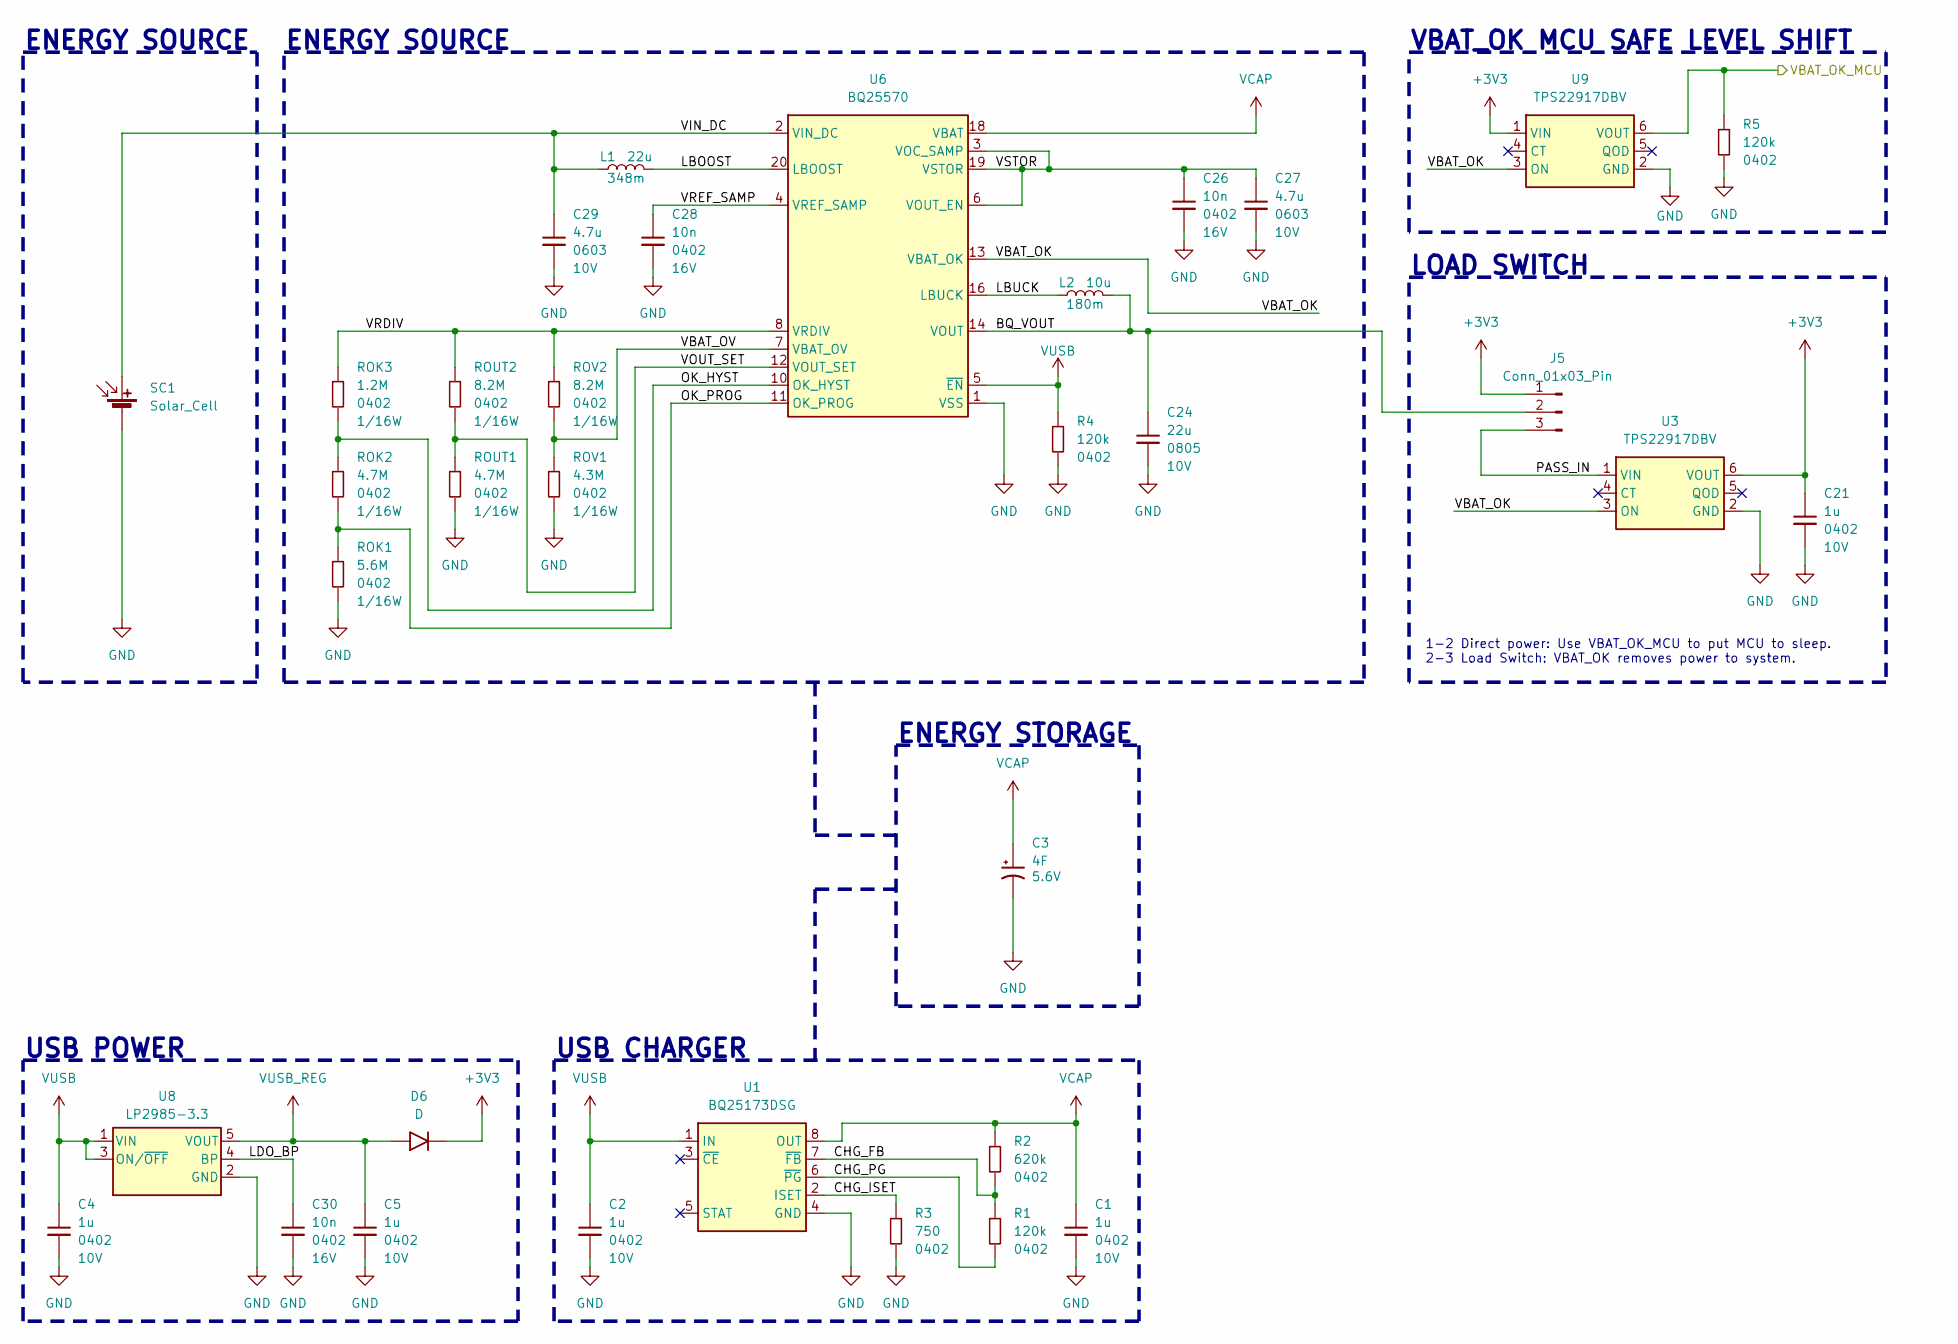
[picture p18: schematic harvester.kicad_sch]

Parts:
C1, C2, C4, C5, C21: 1u; C_0402_1005Metric; Voltage Rating 10V; Part Number GRM155Z71A105KE01J
C3: 4F; CAP_MAL219691154E3_VIS; Voltage Rating 5.6V; Part Number MAL219691154E3
C24: 22u; C_0805_2012Metric; Voltage Rating 10V; Part Number GRM21BZ71A226ME15L
C26, C28, C30: 10n; C_0402_1005Metric; Voltage Rating 16V; Part Number GRM155R71C103KA01D
C27, C29: 4.7u; C_0603_1608Metric; Voltage Rating 10V; Part Number GRM188Z71A475ME15D
D6: D; D_SOD-323; Part Number RB751V40,115
J5: Conn_01x03_Pin; PinHeader_1x03_P2.54mm_Vertical
L1: 22u; IND_TAIYO_NRS4018_TAY; Part Number NRS4018T220MDGJ
L2: 10u; IND_TAIYO_NRS4018_TAY; Part Number NRS4018T100MDGJ
R1, R4, R5: 120k; R_0402_1005Metric; Part Number RC0402FR-07120KL
R2: 620k; R_0402_1005Metric; Part Number RC0402FR-07620KL
R3: 750; R_0402_1005Metric; Part Number RC0402FR-13750RL
ROK1: 5.6M; R_0402_1005Metric; Part Number RC0402FR-075M6L
ROK2: 4.7M; R_0402_1005Metric; Part Number RC0402FR-074M7L
ROK3: 1.2M; R_0402_1005Metric; Part Number RC0402FR-071M2L
ROUT1: 4.7M; R_0402_1005Metric; Part Number RC0402FR-074M7L
ROUT2: 8.2M; R_0402_1005Metric; Part Number RC0402FR-078M2L
ROV1: 4.3M; R_0402_1005Metric; Part Number RC0402FR-074M3L
ROV2: 8.2M; R_0402_1005Metric; Part Number RC0402FR-078M2L
SC1: Solar_Cell; KXOB25-05X3F_IXY; Part Number KXOB25-12X1F-TR
U1: BQ25173DSG; WSON-8-1EP_2x2mm_P0.5mm_EP0.9x1.6mm; Part Number BQ25173DSGR
U3, U9: TPS22917DBV; SOT-23-6; Part Number TPS22917DBVR
U6: BQ25570; QFN-20-1EP_3.5x3.5mm_P0.5mm_EP2x2mm; Part Number BQ25570RGRR
U8: LP2985-3.3; SOT-23-5; Part Number LP2985-33DBVR

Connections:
+3V3: C21.1, D6.1 (K), J5.1, U3.6 (VOUT), U9.1 (VIN); also elsewhere on the board
/harvester/BQ_VOUT: C24.1, J5.2, L2.2, U6.14 (VOUT)
/harvester/CHG_FB: R1.1, R2.2, U1.7 (~FB)
/harvester/CHG_ISET: R3.1, U1.2 (ISET)
/harvester/CHG_PG: R1.2, U1.6 (~PG)
/harvester/LBOOST: L1.2, U6.20 (LBOOST)
/harvester/LBUCK: L2.1, U6.16 (LBUCK)
/harvester/LDO_BP: C30.1, U8.4 (BP)
/harvester/OK_HYST: ROK2.1, ROK3.2, U6.10 (OK_HYST)
/harvester/OK_PROG: ROK1.1, ROK2.2, U6.11 (OK_PROG)
/harvester/PASS_IN: J5.3, U3.1 (VIN)
/harvester/VBAT_OK: U3.3 (ON), U6.13 (VBAT_OK), U9.3 (ON)
/harvester/VBAT_OK_MCU: R5.1, U9.6 (VOUT); also elsewhere on the board
/harvester/VBAT_OV: ROV1.1, ROV2.2, U6.7 (VBAT_OV)
/harvester/VIN_DC: C29.1, L1.1, SC1.1 (+), U6.2 (VIN_DC)
/harvester/VOUT_SET: ROUT1.1, ROUT2.2, U6.12 (VOUT_SET)
/harvester/VRDIV: ROK3.1, ROUT2.1, ROV2.1, U6.8 (VRDIV)
/harvester/VREF_SAMP: C28.1, U6.4 (VREF_SAMP)
/harvester/VSTOR: C26.1, C27.1, U6.3 (VOC_SAMP), U6.6 (VOUT_EN), U6.19 (VSTOR)
GND: C1.2, C2.2, C3.2, C4.2, C5.2, C21.2, C24.2, C26.2, C27.2, C28.2, C29.2, C30.2, R3.2, R4.2, R5.2, ROK1.2, ROUT1.2, ROV1.2, SC1.2 (-), U1.4 (GND), U1.9 (GND), U3.2 (GND), U6.1 (VSS), U6.9 (VSS), U6.15 (VSS), U6.17 (VSS), U6.21 (VSS), U8.2 (GND), U9.2 (GND); also elsewhere on the board
VCAP: C1.1, C3.1, R2.1, U1.8 (OUT), U6.18 (VBAT)
VUSB: C2.1, C4.1, R4.1, U1.1 (IN), U6.5 (~EN), U8.1 (VIN), U8.3 (ON/~OFF); also elsewhere on the board
VUSB_REG: C5.1, D6.2 (A), U8.5 (VOUT); also elsewhere on the board

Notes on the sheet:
USB CHARGER
LOAD SWITCH
ENERGY STORAGE
VBAT_OK MCU SAFE LEVEL SHIFT
ENERGY SOURCE
USB POWER
1-2 Direct power: Use VBAT_OK_MCU to put MCU to sleep. 2-3 Load Switch: VBAT_OK removes power to system.

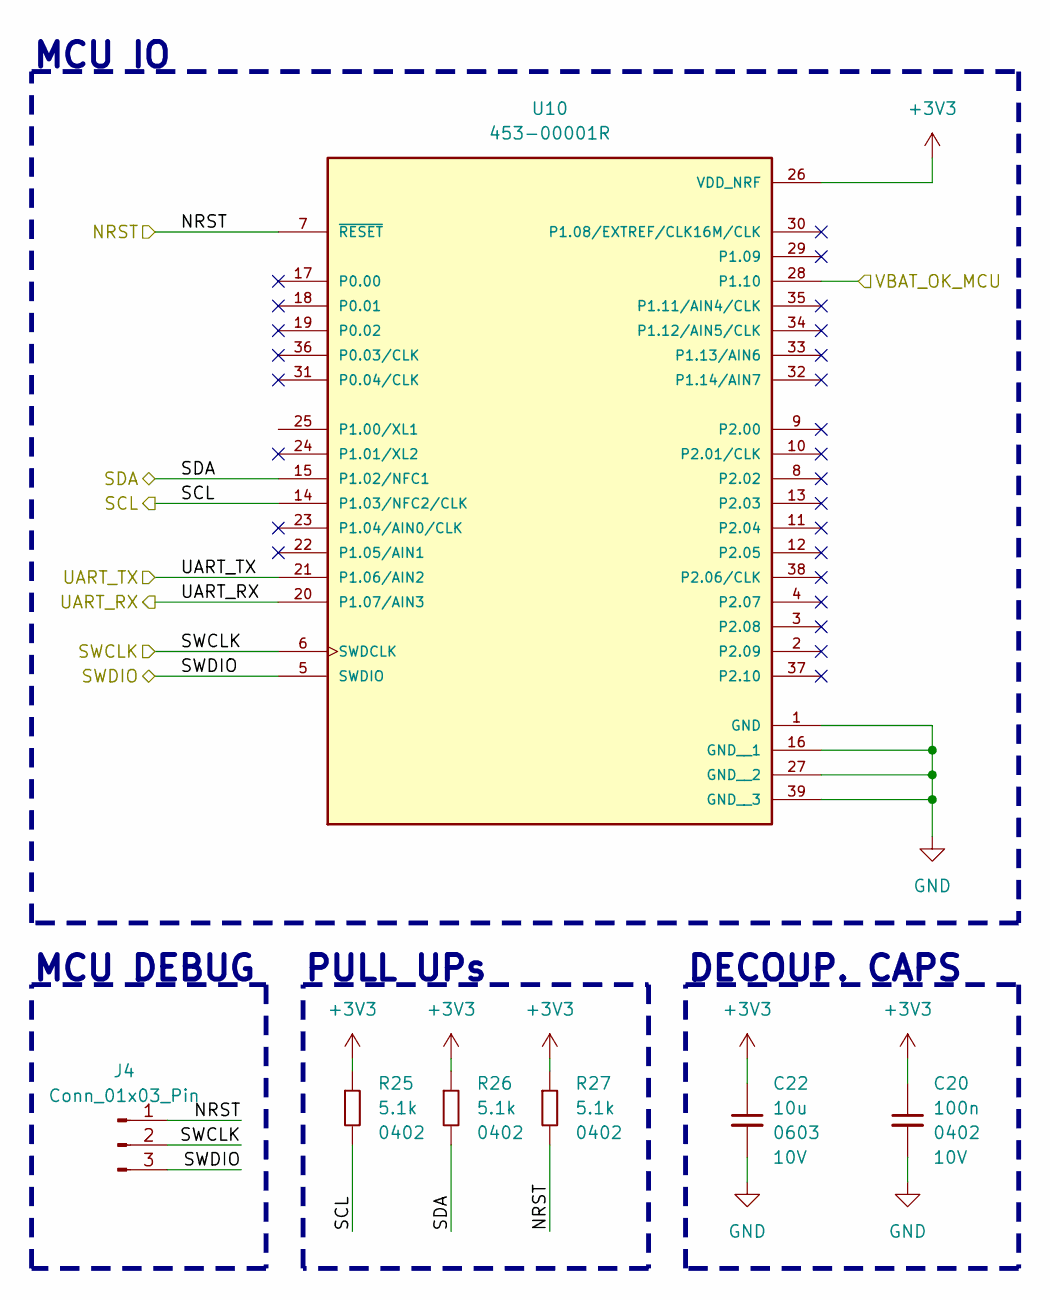
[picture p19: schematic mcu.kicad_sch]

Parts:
C20: 100n; C_0402_1005Metric; Voltage Rating 10V; Part Number GRM155R71A104KA01J
C22: 10u; C_0603_1608Metric; Voltage Rating 10V; Part Number GRM188Z71A106KA73D
J4: Conn_01x03_Pin; PinHeader_1x03_P2.54mm_Vertical
R25, R26, R27: 5.1k; R_0402_1005Metric; Part Number RC0402FR-135K1L
U10: 453-00001R; XCVR_453-00001R; PARTREV 1.8

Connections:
+3V3: C20.1, C22.1, R25.1, R26.1, R27.1, U10.26 (VDD_NRF); also elsewhere on the board
/harvester/VBAT_OK_MCU: U10.28 (P1.10); also elsewhere on the board
/mcu/NRST: J4.1, R27.2, U10.7 (~RESET); also elsewhere on the board
/mcu/SCL: R25.2, U10.14 (P1.03/NFC2/CLK); also elsewhere on the board
/mcu/SDA: R26.2, U10.15 (P1.02/NFC1); also elsewhere on the board
/mcu/SWCLK: J4.2, U10.6 (SWDCLK); also elsewhere on the board
/mcu/SWDIO: J4.3, U10.5 (SWDIO); also elsewhere on the board
/mcu/UART_RX: U10.20 (P1.07/AIN3); also elsewhere on the board
/mcu/UART_TX: U10.21 (P1.06/AIN2); also elsewhere on the board
GND: C20.2, C22.2, U10.1 (GND), U10.16 (GND__1), U10.27 (GND__2), U10.39 (GND__3); also elsewhere on the board

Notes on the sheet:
MCU IO
PULL UPs
DECOUP. CAPS
MCU DEBUG


Board: 4 copper layers, 65.0 x 52.5 mm, 79 parts (0 on the bottom side), 60 nets.

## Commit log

2025-08-07 added pdf schematic for davebot
2025-08-08 updated schematics after some checks to the harvester logic
    [bq25505_70_Design_Help_V1_3.xlsx, bq25570_SolarAppDesignExample_V1p3.xlsx, harvester.kicad_sch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]
2025-08-08 added first pass to layout
    [core.kicad_pcb]
2025-08-11 Initial pass at routing main circuit components
    [core.kicad_pcb]
2025-08-12 Updated with cap and connector
    [core.kicad_pcb, harvester.kicad_sch, system.kicad_sch]
2025-08-18 updated layout with footprint changes
    [core.kicad_pcb, harvester.kicad_sch, system.kicad_sch]
2025-08-19 added variables
    [core.kicad_sch, harvester.kicad_sch, system.kicad_sch]
2025-08-21 Minor part choice changes and appropriate board updates
    [harvester.kicad_sch, system.kicad_sch]
2025-08-21 Adding initial design
    [case_body.step, case_lid.step]
2025-08-26 adding ambient sensor board
    [ambient.kicad_pcb, ambient.kicad_sch]
2025-08-26 bom updates
    [core.kicad_pcb, harvester.kicad_sch, system.kicad_sch]
2025-08-27 updated technical sheet
    [ambient.kicad_pcb, ambient.kicad_sch, ambient.step]
2025-08-28 updated harvester configuration resistors and removed cap solder link
    [bq25505_70_Design_Help_V1_3.xlsx, core.kicad_pcb, harvester.kicad_sch]
2025-08-28 Updated charger configuration
    [harvester.kicad_sch, system.kicad_sch]
2025-08-28 corrected pin mating to sensor module
    [ambient.kicad_pcb, core.kicad_pcb]
2025-08-28 updated drawings
    [ambient.kicad_pcb, ambient.kicad_sch, ambient.step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]
2025-08-28 updated bom information
    [ambient.kicad_sch]
2025-08-28 updated CAD models
    [ambient.step, case_body.step, case_lid.step]
2025-08-29 corrections from footprint updates and manufacture file exports
    [ambient.kicad_pcb, ambient.kicad_sch, ambient.step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]
2025-09-01 added rules files and references
    [KiCAD_Custom_DRC_Rules_for_PCBWay.kicad_pcb, KiCAD_Custom_DRC_Rules_for_PCBWay.kicad_sch, TemperatureSensor.kicad_pcb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]
2025-09-01 moved resistor to be in alignment
    [ambient.kicad_pcb]
2025-09-01 updated board cut thickness
    [ambient.kicad_pcb, core.kicad_pcb]
